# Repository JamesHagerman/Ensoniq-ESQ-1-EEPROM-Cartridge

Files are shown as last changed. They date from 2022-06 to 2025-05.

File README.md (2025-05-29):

# Ensoniq ESQ-1 EEPROM Cartridge

This repo contains an open source hardware design for a EEPROM-based patch storage cartridge for the Ensoniq ESQ-1 and SQ-80 hybrid synthesizers..

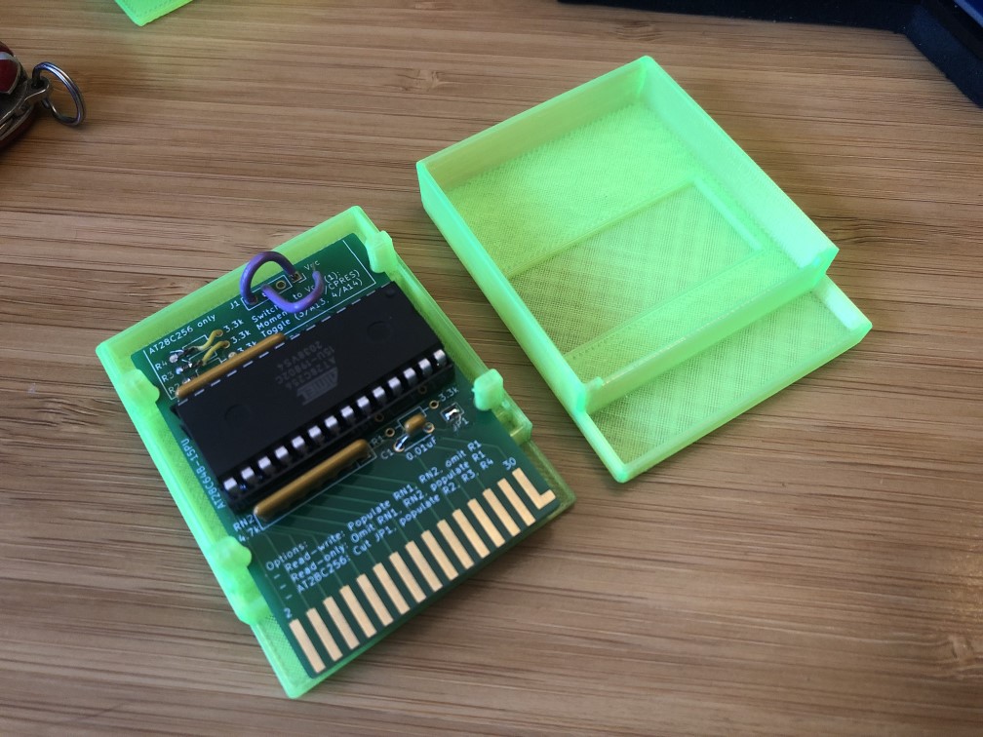
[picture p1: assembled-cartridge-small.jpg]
A photo of the assembled EEPROM cartridge PCB and two halves of the 3D printed enclosure


## Assembly Details

*Note: Do not populate C1! Field testing has shown that it decreases stability of the cartridge.*

Latest assembly instructions and errata can be found in the PDF at the root of this repo.

The PCB is designed to support AT28C64 and AT28C256 (or similar) EEPROM's. The larger EEPROM option can be controlled using 2 switches (purple wires in the photo below).

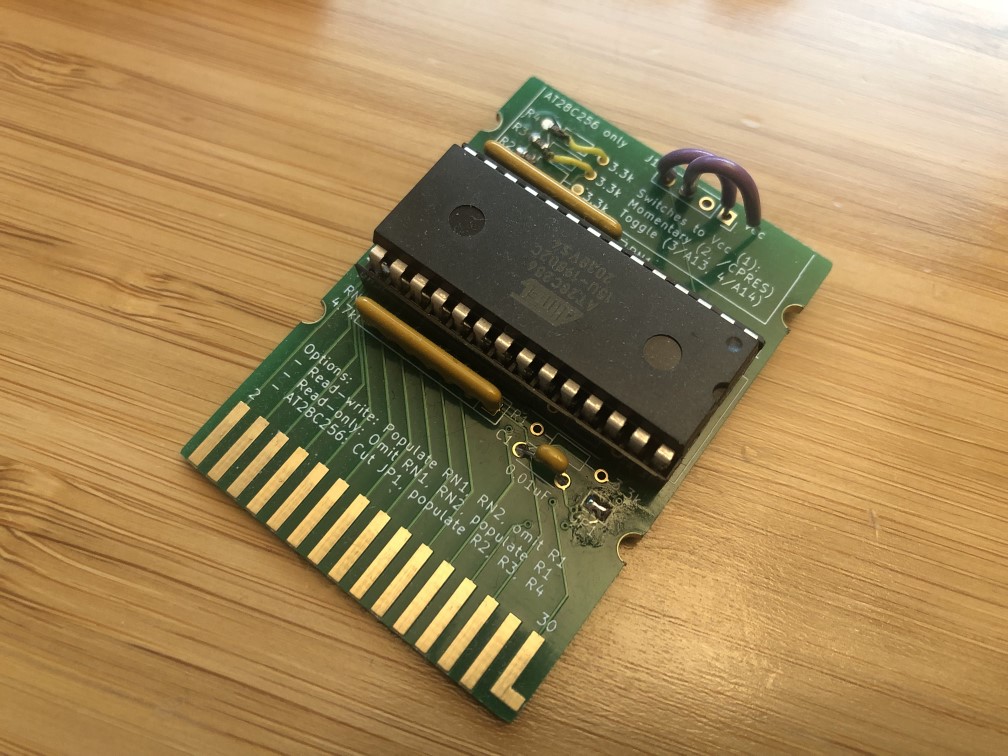
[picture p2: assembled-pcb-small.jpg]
A photo of the assembled EEPROM cartridge PCB and two halves of the 3D printed enclosure


The cartridge can also be configured as a "read-only" cartridge with some reducion in parts count.

The current 3D printed enclosure design is provided as a Fusion 360 file. The two halves of the case are inteded to be held together either using a press fit or with clear packing tape. Not elegant, but it works.

## Where can I purchase one?

*Note: PCBs are currently out of stock at the ZenSynth Tindie store and Reverb pending an updated design and PCB run. Existing PCBs can be purchased from Mono Tanz here: https://monotanz.de/product/diy-ensoniq-esq-1-sq-80-eeprom-cartridge/*

Unpopulated PCB's can be ordered from the ZenSynth store on Tindie: 

https://www.tindie.com/products/zensynth/oshdiy-ensoniq-esq-1sq-80-eeprom-cartridge/

Or on Reverb:

https://reverb.com/item/62807297-ensoniq-esq-1-sq-80-eeprom-cartridge-pcb-direct-from-pcb-designer

Enclosures can be 3D printed using the STL files provided in this repo. I had good luck printing the cartriges in PETG on a Prusa i3 mk3.

## BOM?

I don't follow an exact Bill of Materials, but I exported this from my Mouser project.

*Note: Please make sure you check which EEPROM you're ordering! You only need one but two are listed below!*

```
ENSONIQ ESQ-1/SQ-80 EEPROM CARTRIDGE									
Mouser #	Mfr. #	Manufacturer	Customer #	Description	RoHS	Lifecycle	Order Qty.	Price (USD)	Ext.: (USD)
556-AT28C64B15PU	AT28C64B-15PU	Microchip		EEPROM 64K 8K x 8 150 ns 4.5V-5.5V	RoHS Compliant		1	$5.84	$5.84
556-AT28C25615PU	AT28C256-15PU	Microchip		EEPROM 256K 32K x 8 150 ns 4.5V-5.5V	RoHS Compliant		1	$12.33	$12.33
652-4607X-1LF-4.7K	4607X-101-472LF	Bourns		Resistor Networks & Arrays 7pins 4.7Kohms Bussed	RoHS Compliant By Exemption		2	$0.47	$0.94
594-K103J20C0GH53H5G	K103J20C0GH53H5G	Vishay		Multilayer Ceramic Capacitors MLCC - Leaded 100V 10nF 5% C0G e3 Auto	RoHS Compliant		1	$0.75	$0.75
279-LR1F3K3	LR1F3K3	TE Connectivity		Metal Film Resistors - Through Hole 3.3KOhm 3/5W 50PPM	RoHS Compliant		2	$0.16	$0.32
571-1-2199299-2	1-2199299-2	TE Connectivity		IC & Component Sockets 28P DIP SKT 600 CL LADDER	RoHS Compliant		1	$0.67	$0.67
```

*Additional Note: These EEPROM's have been hit by the component shortage. Microchip/Atmel EEPROM chips would be ideal, but the part only really need to be pin compatible 28c64/28c256 EEPROM's. Check Jameco's stock if you can't find any from your normal supplier! They have a good history of keeping 'em on the shelves. (i.e. https://www.jameco.com/z/28C256-25-Major-Brands-IC-28C256-25IC-EEPROM-256K-Bit-CMOS-Parallel_74878.html)*

## Assembly Instructions?

Instructions to assembly the board can be found in the `assembly-notes-and-schematic-vX.X.X.pdf` file in the root directory of this repo.

## Initialization Steps

After assembly, you have to "initialize" the cartridge before using it. You can do this by saving the synths internal patches to EEPROM. Here are some steps:

```
    Power up the synth
    Plug in the cartridge
    Press “STORAGE”
    Press the button under “CARTRIDGE”
    Press the button for “INT TO CART A” or “INT TO CART B”
    Press the button for “YES”
```
## Errata

### Writes are unstable

If you are having issues initializing the cartridge or writing patches to the cartridge, *please consider removing `C1` from the board and try the initialization process again.*

Other builders ran into stability issues and helped greatly in identifying potential fixes (Thanks Ivan!). This was somewhat difficult to track down due to the age and various condition of people's Ensoniq synths.

### Cartridge detect circuitry is incorrect

As noted in the errata section of the schematic PDF, please (i.e. do not populate) R2, do not cut JP1, and do not short Pin 2 of J1 to Vcc at any time.

There are no good examples of the associated `CPRES` line being used effectively on other cartridges and I didn't do enough testing before getting boards assembled. I'll remove these components if another run of boards ends up happening.

## I'm stuck. How do I get help?

If you purchased the board from me, you should have my contact information. Otherwise, please consider opening a new [GitHub issue](https://github.com/JamesHagerman/Ensoniq-ESQ-1-EEPROM-Cartridge/issues) including additional context about where you're stuck. I'll do my best to help! 

## Additional Resources

A very special thanks to Rainer Buchty for his help bringing this project to life! Thank you for the chats and resources!

If you haven't already found his wonderfully detailed site dedicated to Ensoniq synthesizers, you're missing out: http://www.buchty.net/ensoniq/

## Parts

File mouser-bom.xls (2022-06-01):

ENSONIQ ESQ-1/SQ-80 EEPROM CARTRIDGE
Mouser # | Mfr. # | Manufacturer | Customer # | Description | RoHS | Lifecycle | Order Qty. | Price (USD) | Ext.: (USD)
556-AT28C64B15PU | AT28C64B-15PU | Microchip |  | EEPROM 64K 8K x 8 150 ns 4.5V-5.5V | RoHS Compliant |  | 1 | $5.31 | $5.31
652-4607X-1LF-4.7K | 4607X-101-472LF | Bourns |  | Resistor Networks & Arrays 7pins 4.7Kohms Bussed | RoHS Compliant By Exemption |  | 2 | $0.42 | $0.84
594-K103J20C0GH53H5G | K103J20C0GH53H5G | Vishay |  | Multilayer Ceramic Capacitors MLCC - Leaded 100V 10nF 5% C0G e3 Auto | RoHS Compliant | New Product | 1 | $0.75 | $0.75
279-LR1F3K3 | LR1F3K3 | TE Connectivity |  | Metal Film Resistors - Through Hole 3.3KOhm 3/5W 50PPM | RoHS Compliant |  | 4 | $0.15 | $0.60

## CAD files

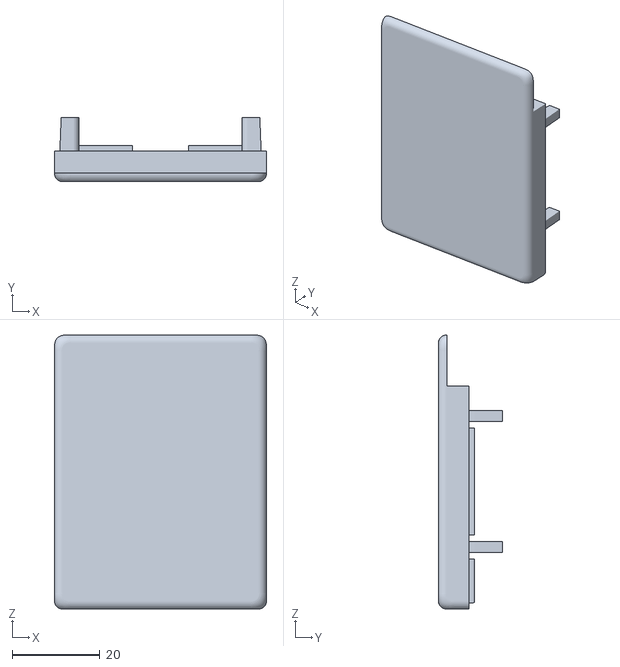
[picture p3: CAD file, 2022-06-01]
enclosure/stl/top-press-fit-alternate.stl
48.3 x 14.6 x 62.4

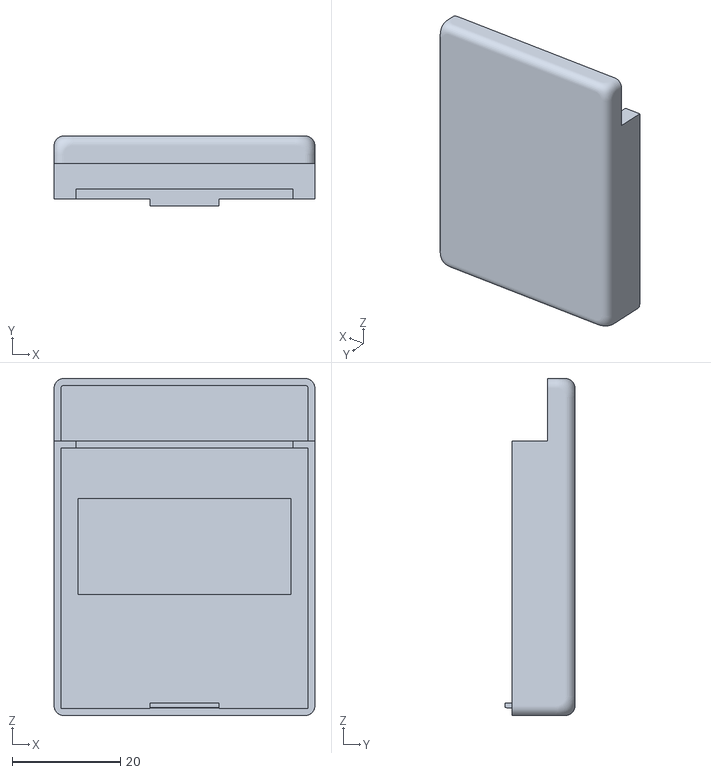
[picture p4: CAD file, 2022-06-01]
enclosure/stl/top.stl
48.3 x 13.0 x 62.4

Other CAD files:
enclosure/stl/bottom.stl
enclosure/Ensoniq Cartridge Case EEPROM v32.f3d

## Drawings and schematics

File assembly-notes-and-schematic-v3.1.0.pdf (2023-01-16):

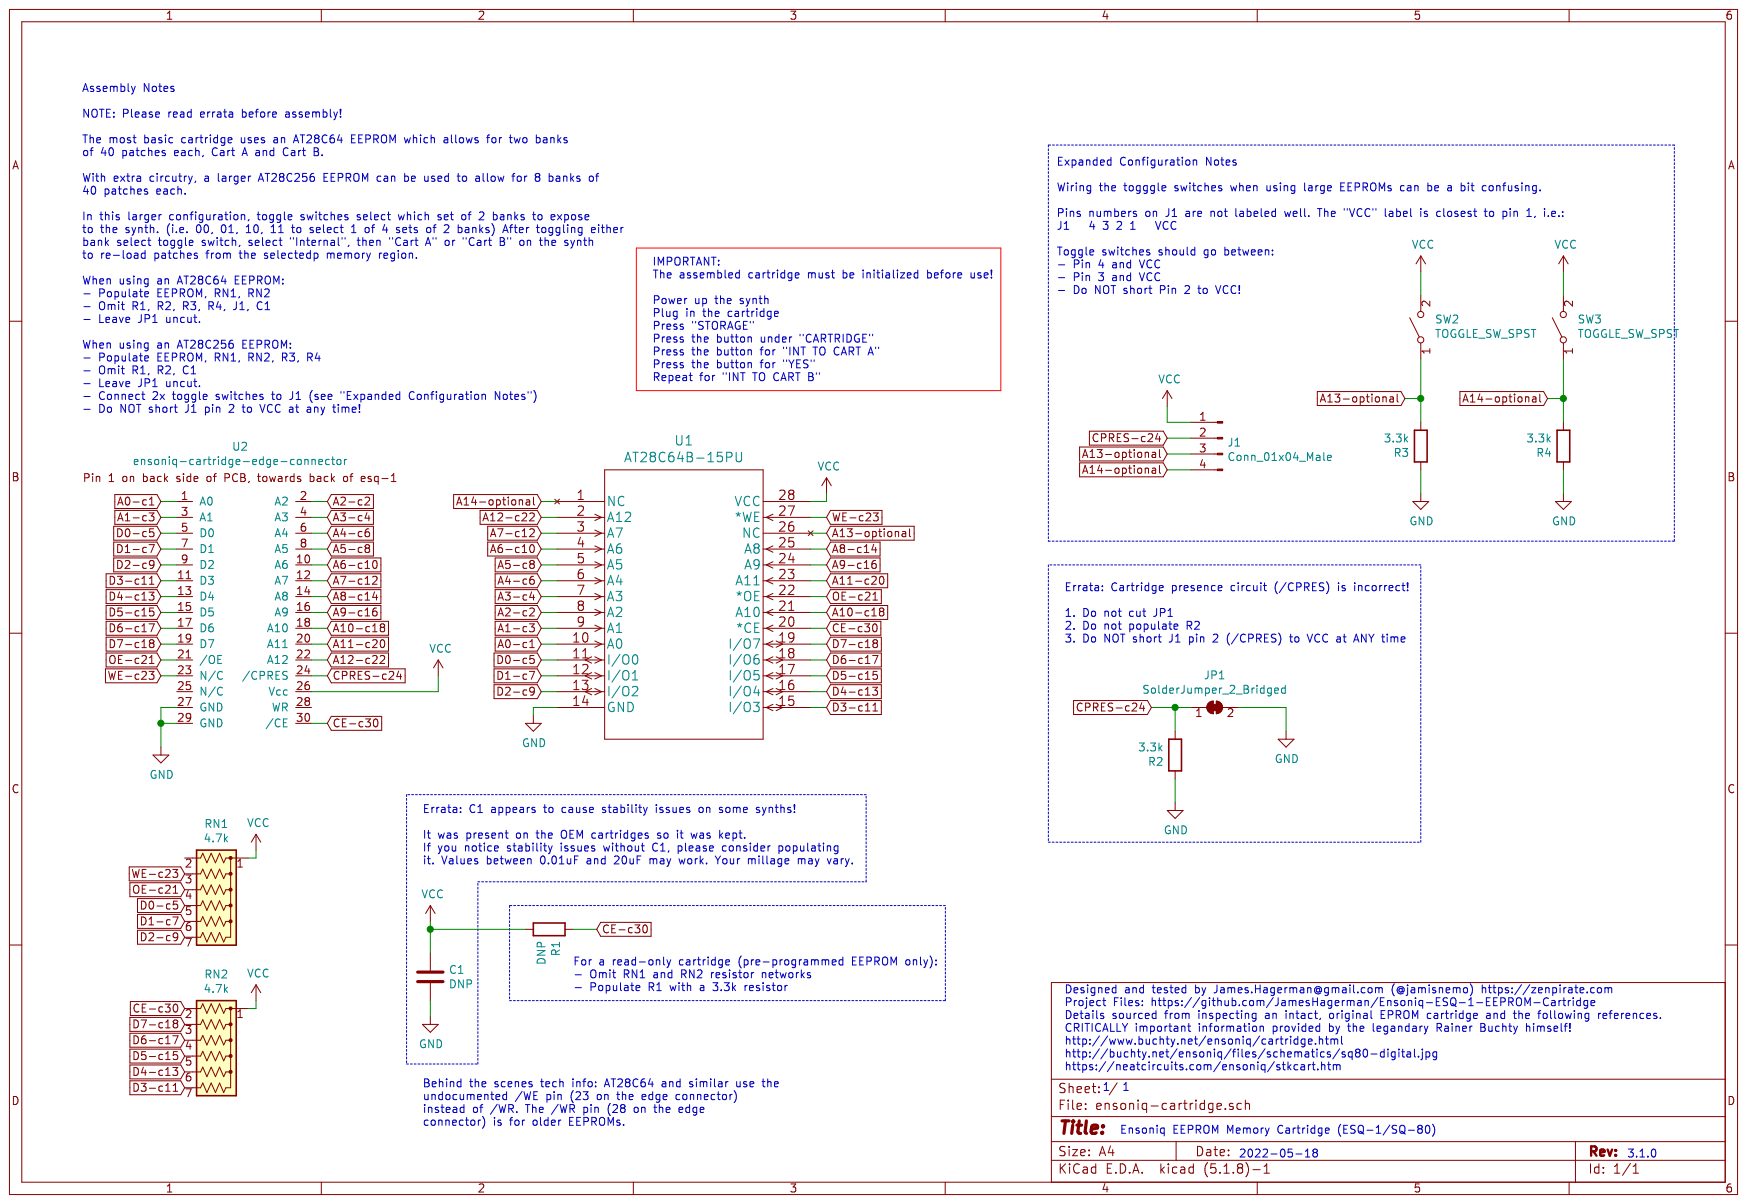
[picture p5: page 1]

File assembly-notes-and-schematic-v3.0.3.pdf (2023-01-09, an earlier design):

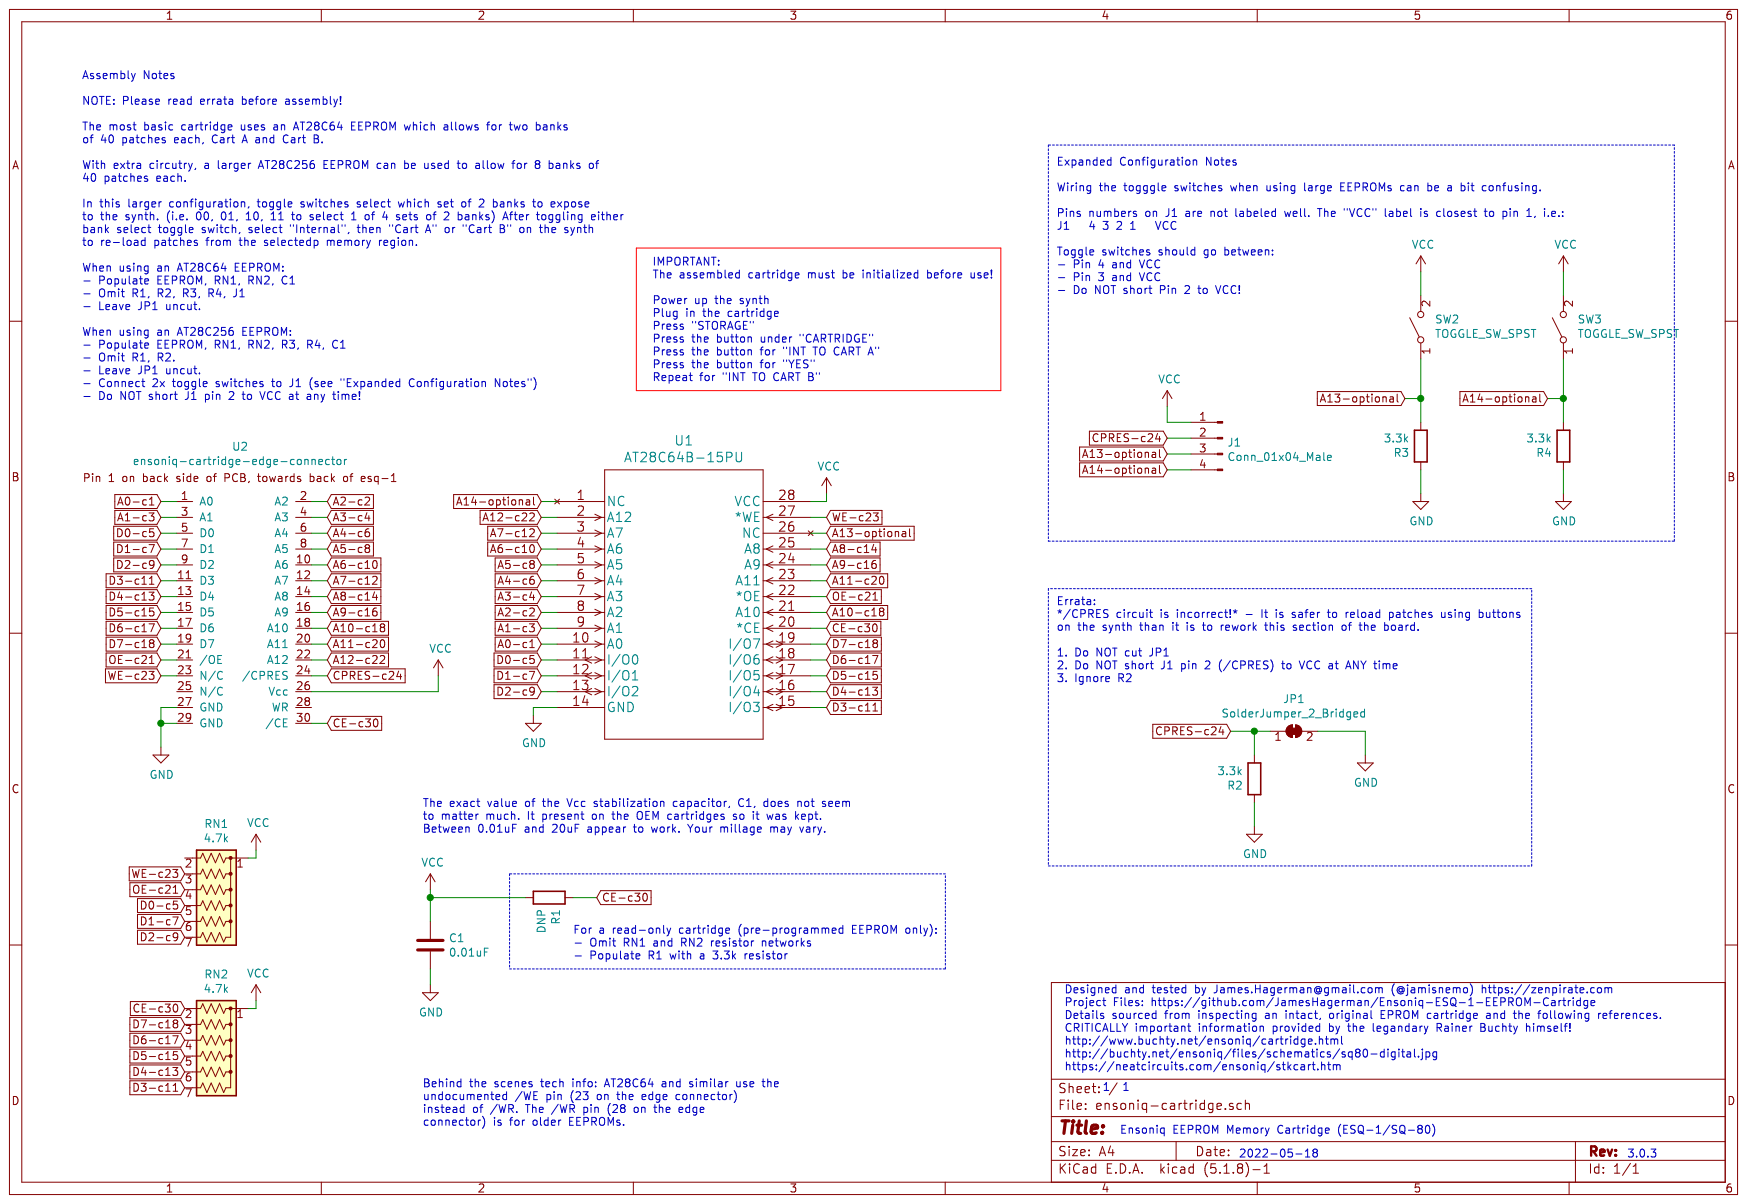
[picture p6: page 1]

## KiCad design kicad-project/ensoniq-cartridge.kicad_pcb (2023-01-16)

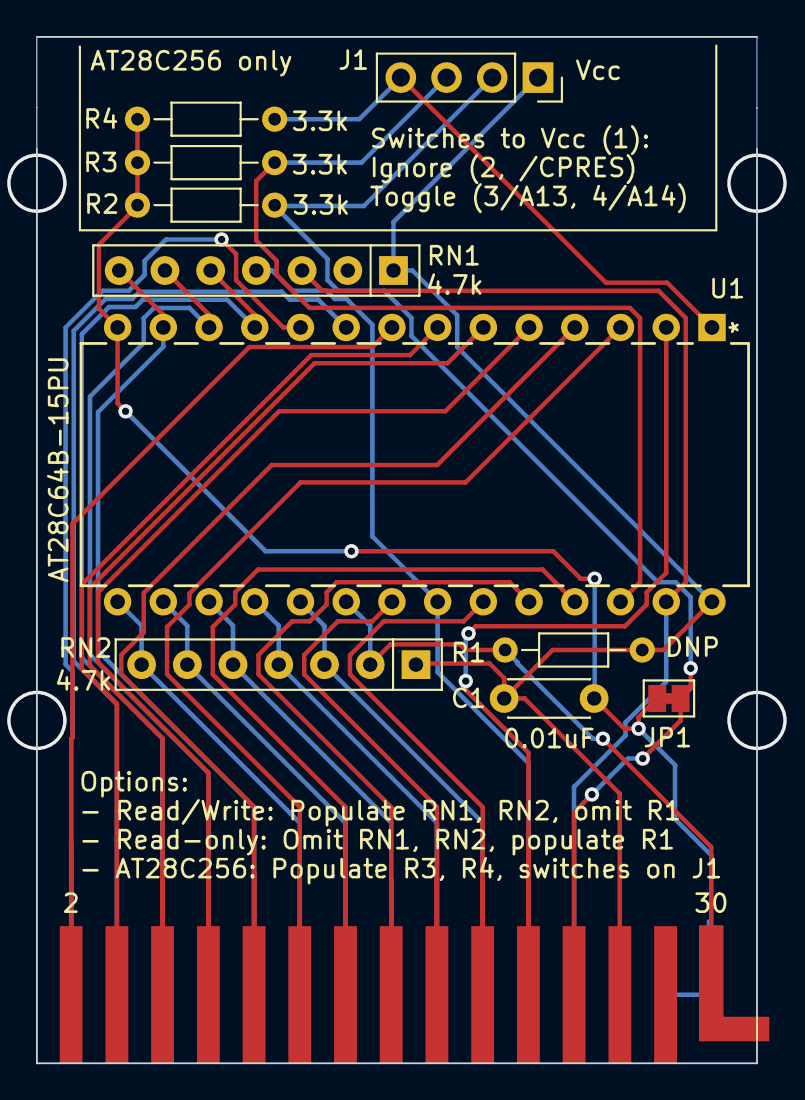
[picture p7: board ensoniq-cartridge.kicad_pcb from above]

Board: 2 copper layers, 40.0 x 57.0 mm, 11 parts (0 on the bottom side), 29 nets.

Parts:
C1: 0.01uF; C_Disc_D4.3mm_W1.9mm_P5.00mm
J1: Conn_01x04_Male; PinSocket_1x04_P2.54mm_Vertical
JP1: SolderJumper_2_Bridged; SolderJumper-2_P1.3mm_Bridged_Pad1.0x1.5mm
R1: DNP; R_Axial_DIN0204_L3.6mm_D1.6mm_P7.62mm_Horizontal
R2, R3, R4: 3.3k; R_Axial_DIN0204_L3.6mm_D1.6mm_P7.62mm_Horizontal
RN1, RN2: 4.7k; R_Array_SIP7
U1: AT28C64B-15PU
U2: ensoniq-cartridge-edge-connector

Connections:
A0-c1: U1.10, U2.1
A1-c3: U1.9, U2.3
A2-c2: U1.8, U2.2
A3-c4: U1.7, U2.4
A4-c6: U1.6, U2.6
A5-c8: U1.5, U2.8
A6-c10: U1.4, U2.10
A7-c12: U1.3, U2.12
A8-c14: U1.25, U2.14
A9-c16: U1.24, U2.16
A10-c18: U1.21, U2.18
A11-c20: U1.23, U2.20
A12-c22: U1.2, U2.22
A13-optional: J1.3, R3.2, U1.26
A14-optional: J1.4, R4.2, U1.1
CE-c30: R1.1, RN2.2, U1.20, U2.30
CPRES-c24: J1.2, JP1.1, R2.2, U2.24
D0-c5: RN1.5, U1.11, U2.5
D1-c7: RN1.6, U1.12, U2.7
D2-c9: RN1.7, U1.13, U2.9
D3-c11: RN2.7, U1.15, U2.11
D4-c13: RN2.6, U1.16, U2.13
D5-c15: RN2.5, U1.17, U2.15
D6-c17: RN2.4, U1.18, U2.17
D7-c18: RN2.3, U1.19, U2.19
GND: C1.2, JP1.2, R2.1, R3.1, R4.1, U1.14, U2.27, U2.29
OE-c21: RN1.4, U1.22, U2.21
VCC: C1.1, J1.1, R1.2, RN1.1, RN2.1, U1.28, U2.26
WE-c23: RN1.3, U1.27, U2.23

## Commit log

2022-06-01 Adding KiCad PCB files. Adding Gerber files. Adding Enclosure Fusion 360 file and STL files. Adding BoM. Adding PDF documenting latest assembly instructions and errata.
    [Ensoniq Cartridge Case EEPROM v32.f3d, bottom.stl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]
2022-06-01 Adding Readme and reference photos of the completed board and enclosure.
2022-11-02 Update README.md
    Adding notes about sourcing an enclosure
2022-11-02 Update README.md
    Adding notes about the EEPROM's on the BoM and adding suggestion of using Jameco to source hard-to-find parts
2022-12-05 Updating schematic with initialization steps and adding schematic image to repo.
    [ensoniq-cartridge.sch]
2023-01-09 Updating schamtic and PDF build instructions to be more human readable.
    [ensoniq-cartridge.sch]
2023-01-16 Updating README.me and assembly notes and schematic PDF to include stability suggestions relating to C1.
    [ensoniq-cartridge.kicad_pcb, ensoniq-cartridge.sch]
2025-05-29 Update README.md with note about C1 instability and updated source for PCBs
